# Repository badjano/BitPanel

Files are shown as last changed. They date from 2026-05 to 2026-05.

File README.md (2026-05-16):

# BitPanel

BitPanel is a small **open-source toy**: toggles set a **24-bit RGB** colour (8 bits per channel) on one LED, with a **Raspberry Pi Pico** (MicroPython) reading switches via shift registers and applying a few playful transforms.

This repo exists so **other people can build it**. Nothing here is sold or warranted—see **[Disclaimer](#disclaimer)** below.

**Play in the browser:** [https://badjano.github.io/BitPanel/](https://badjano.github.io/BitPanel/) (GitHub Pages — 24-bit RGB toggles, no install).

## Documentation

| Guide | Contents |
|---|---|
| **[web/README.md](web/README.md)** | Browser sim — 24 toggles, flip RGB bits (no hardware) |
| **[blender/README.md](blender/README.md)** | Parametric panel plate, STL export, printing and mechanical fit-up |
| **[pico/README.md](pico/README.md)** | Wiring (shift registers, buttons, NeoPixel), firmware, bring-up |
| **[blender/export/README.md](blender/export/README.md)** | Pre-built `bitpanel_plate.stl` (optional; regenerate from the script) |

## Parts (starting point)

| Item | Notes |
|---|---|
| Raspberry Pi Pico | MicroPython build with `neopixel` support |
| 74HC165 shift registers × 4 | Panel switch inputs (32 lines on default plate; **24 bits** drive RGB) |
| Toggles | **24** for colour (R/G/B × 8), or **32** on the default plate with eight spare / unmapped — match `BIT_PERM` in `pico/hw_config.py` |
| Tactile switches × 4 | Random / Organize / Shift up / Shift down |
| WS2812 (“NeoPixel”) LED × 1 | Or small NeoPixel PCB |
| Resistors | Pull-ups as needed (Pico has internal pulls on GPIO buttons) |
| Power | USB for Pico; NeoPixel level / voltage per your pixel datasheet |
| Fasteners | Panel screws for toggles; M3 or similar for corner holes if used |
| Wire, solder, perfboard or PCB | Optional custom PCB for shift registers |

Always measure **your** switch bushings and pixels before printing. See **[blender/README.md](blender/README.md)** for plate geometry.

## Assembly order (overview)

1. Print and dry-fit the plate — **[blender/README.md](blender/README.md)**
2. Mount toggles, mode buttons, and LED
3. Wire electronics and flash firmware — **[pico/README.md](pico/README.md)**
4. Tune `hw_config.py` and `PARAMETERS` in `bitpanel_case.py` to match your build

## Troubleshooting

| Symptom | Where to look |
|---|---|
| Wrong bit order | [pico/README.md](pico/README.md) — `SHIFT_MSB_FIRST`, `BIT_PERM` |
| Random flicker / bad reads | [pico/README.md](pico/README.md) — power, wiring length, clock vs data |
| LED wrong colour | [pico/README.md](pico/README.md) — RGB packing, NeoPixel wiring |
| Holes / fit wrong | [blender/README.md](blender/README.md) — `PARAMETERS`, re-export STL |

## Safety

- Double-check **power polarity** before applying USB or LED supply.
- NeoPixels can draw **surprising current** at full white — size wiring and USB supply accordingly.

## Licensing

- **Software** (`pico/`): **[MIT License](LICENSE)**
- **Hardware design materials** (`blender/` and derivatives): **[CERN-OHL-P-Version-2](LICENSE-HARDWARE)**

SPDX: `MIT` (software), `CERN-OHL-P-2.0` (hardware). If you redistribute adapted hardware designs, follow the notice requirements in **`LICENSE-HARDWARE`**.

## Disclaimer

**Use at your own risk.** BitPanel is **just a fun project**: hobby-grade firmware, generic mechanical assumptions, and no certification or compliance guarantees (electrical safety, EMC, eye safety from LEDs, etc.). You are responsible for how you power it, wire it, mount it, and who uses it. The authors and contributors are **not liable** for damage or injury arising from building or using this project.

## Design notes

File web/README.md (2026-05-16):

# BitPanel — web simulator

Simple browser version: **24 buttons** flip the bits of a **24-bit RGB** colour (same layout as [`pico/bits_ops.py`](../pico/bits_ops.py)).

**Play online:** [https://badjano.github.io/BitPanel/](https://badjano.github.io/BitPanel/)

| Bit index | Channel |
|---|---|
| 0–7 | Red |
| 8–15 | Green |
| 16–23 | Blue |

## Run locally

ES modules need a local server (opening `index.html` as `file://` may block imports).

```bash
cd web
python -m http.server 8080
```

Then open **http://localhost:8080/**

## GitHub Pages

Pushes to `main` deploy automatically via [`.github/workflows/pages.yml`](../.github/workflows/pages.yml).  
Repo **Settings → Pages → Build and deployment** should use **GitHub Actions** (enabled on first workflow run).

← **[Project overview](../README.md)**

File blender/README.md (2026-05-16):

# BitPanel — panel plate (Blender)

Parametric **top plate** for an **8×4** toggle grid (32 holes on the default layout), four mode buttons, one LED hole, corner mounts, and an underside **Pico pocket**. Firmware colour is **24-bit RGB** — wire **24** toggles to colour bits or map 32 positions via `pico/hw_config.py` (`BIT_PERM`).

← **[Project overview](../README.md)** · Firmware & wiring: **[pico/README.md](../pico/README.md)**

## Files

| File | Role |
|---|---|
| `bitpanel_case.py` | Build geometry; edit `PARAMETERS` at the top (millimetres) |
| `export/bitpanel_plate.stl` | Example export — see **[export/README.md](export/README.md)** |

## Interactive (Blender UI)

1. Install **Blender 3 LTS or newer** (4.x / 5.x is fine).
2. **Scripting** workspace → **Text → Open** → `bitpanel_case.py` → **Run Script**.

You get mesh **`BitPanel_Plate`**: **8×4** toggle holes, **four** button holes, **one** LED hole, **corner** through-holes, **Pico pocket** on the underside.

### Tune `PARAMETERS`

- `toggle_hole_d_mm` — panel hole for your toggle bushings  
- `hole_pitch_x_mm` / `hole_pitch_y_mm` — centre spacing  
- `btn_*` — mode button row position and diameters  
- `led_*` — LED hole position and diameter  
- `pico_pocket_*` — clearance under the plate (no screw bosses; use pads or a tray)

Export: select plate → **File → Export → STL** (or 3MF).

## Headless STL export

Regenerate without opening the UI:

```bash
blender --background --factory-startup --python blender/bitpanel_case.py
```

`--factory-startup` skips personal add-ons (many fail in `--background` without a GPU UI).

**Steam (Windows PowerShell):**

```powershell
& 'C:\Program Files (x86)\Steam\steamapps\common\Blender\blender.exe' --background --factory-startup --python 'path\to\BitPanel\blender\bitpanel_case.py'
```

Output: **`export/bitpanel_plate.stl`** (folder created automatically).

## Blender MCP (optional)

Blender MCP lets an IDE run Python in Blender (`execute_blender_code`). Typical flow:

1. Install the **Blender addon** from your MCP project → enable in **Edit → Preferences → Add-ons**.
2. Connect from Blender’s MCP sidebar.
3. In **Cursor**: **Settings → MCP → Add server** (follow your MCP package README).

You can run this script via MCP or paste `bitpanel_case.py` into an execute-code action. If MCP is unavailable, use the UI or headless command above.

## Mechanical assembly

1. **Print** the plate; remove supports; test **one** toggle hole and **one** button before mounting all 32.
2. **Mount toggles** from the front; note **which physical position is bit 0** (map in `pico/hw_config.py` via `BIT_PERM` if needed).
3. **Mount** four tactile mode switches.
4. **Install** LED from the front (diffuser optional).
5. **Mount Pico** under the panel (adhesive, standoffs, or separate tray — the script only cuts a **pocket**).
6. **USB** exit is not modelled by default — slot in CAD, drill, or file as needed.

Electronics and firmware: **[pico/README.md](../pico/README.md)**.

## License

Hardware design materials in this folder are under **[CERN-OHL-P-Version-2](../LICENSE-HARDWARE)**.

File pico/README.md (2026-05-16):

# BitPanel — Pico firmware & wiring

**MicroPython** on a **Raspberry Pi Pico**: read panel switches through **four 74HC165** shift registers, drive one **NeoPixel** from a **24-bit RGB** word (8 bits per channel), plus four **mode buttons** on GPIO.

← **[Project overview](../README.md)** · Panel plate: **[blender/README.md](../blender/README.md)**

## Firmware files

| File | Role |
|---|---|
| `main.py` | Main loop, buttons, LED update |
| `hw_config.py` | Pins, `SHIFT_MSB_FIRST`, `BIT_PERM` |
| `shift165.py` | Parallel load + clock in raw switch word (32 lines on default plate) |
| `bits_ops.py` | RGB pack/unpack, random / quantize / rotate |

### Behaviour

- **Panel** sets the baseline colour when any toggle changes.
- **Random** — new random 24-bit colour.
- **Organize** — quantize each RGB channel (steps of 32).
- **Shift up / down** — rotate the **24** RGB bits (colour stays in R/G/B space).

## Wiring

### Shift registers (panel switches, 3 Pico pins)

Four **74HC165** devices chained:

- **PL** (parallel load) — shared → `PIN_SR_PL` (default GP16), active-low load pulse.
- **CLK** — shared → `PIN_SR_CP` (GP17).
- **Serial chain**: **Q7** of chip *n* → serial **in** of chip *n+1*.
- First chip serial **in** often tied **LOW** (match `SHIFT_MSB_FIRST` in `hw_config.py`).
- **CE** / inhibit: enable shifting when clocking (often tied low).

Each ’165 latches eight toggles on **parallel load**; firmware clocks one edge per switch line and samples **DATA** (`shift165.py`). Only **24** mapped bits form the RGB colour (`BIT_PERM`, then `MASK24`).

**Ground**: common between Pico, registers, switches, and LED return.

**Debouncing**: simple stable double-read in firmware; add RC hardware if inputs bounce badly.

### Mode buttons (4×)

Direct GPIO, **internal pull-up**, active **LOW** (default GP20–GP23 in `hw_config.py`).

### NeoPixel

Default data **GP15**. Many pixels want **5 V** data; Pico is **3.3 V** — use a **level shifter**, a **3.3 V–tolerant** pixel, or follow your part’s datasheet. **GND** common with the Pico.

## Install firmware

1. Flash **MicroPython** for Raspberry Pi Pico from [micropython.org](https://micropython.org/download/RPI_PICO/).
2. Mount USB storage; copy all `pico/*.py` files to the Pico root (so `main.py` runs at boot).
3. Confirm **`neopixel`** is available on your build.

## Bring-up

1. Optional: comment out or limit `NeoPixel` writes until wiring is verified.
2. In **Thonny** or **rshell**, toggle one switch and inspect `read_raw()` / panel word after fixing bit order.
3. Wrong colours: adjust `BIT_PERM` / `SHIFT_MSB_FIRST`, or byte order in `bits_ops.word_to_rgb`.

## Troubleshooting

| Symptom | Things to check |
|---|---|
| Wrong bit order | `SHIFT_MSB_FIRST`, chain direction, `BIT_PERM` |
| Random flicker | Power, long data line, clock/load near NeoPixel data |
| Always 0 / 255 | PL polarity, clock idle, wrong pin in `hw_config.py` |
| LED wrong colour | GRB handled by library — test pure R, G, B patterns |

## License

Firmware in this folder is under the **[MIT License](../LICENSE)**.

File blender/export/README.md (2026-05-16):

# Exported plate mesh

| File | Description |
|---|---|
| `bitpanel_plate.stl` | Plate generated from default `PARAMETERS` in [`../bitpanel_case.py`](../bitpanel_case.py) |

← **[Blender guide](../README.md)** · **[Project overview](../../README.md)**

Regenerate after changing switch spacing or hole sizes:

```bash
blender --background --factory-startup --python blender/bitpanel_case.py
```

Commit an updated STL only if you want makers to skip Blender; otherwise they can export locally.

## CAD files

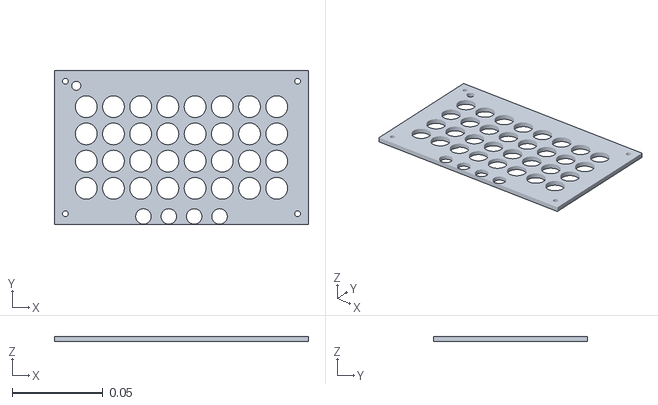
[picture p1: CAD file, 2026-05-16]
blender/export/bitpanel_plate.stl
0.14 x 0.085 x 0.003

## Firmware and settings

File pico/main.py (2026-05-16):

# SPDX-License-Identifier: MIT
"""
BitPanel controller: panel switches → 24-bit RGB NeoPixel, plus modifier buttons.

Colour is always 24 bits (R, G, B × 8). Shift registers may read more switch
lines; only the lower 24 bits are used for the LED after mapping (see MASK24).

Modifier actions (edge-triggered):
  Random     — replace working colour with random 24-bit RGB.
  Organize   — quantize RGB channels to steps (see bits_ops.organize_quantize_rgb).
  Shift up   — rotate the 24 RGB bits left by one (wraps within color bits).
  Shift down — rotate the 24 RGB bits right by one.

Base color follows the panel when switches change; modifiers rewrite ``working``.
"""

import time
from machine import Pin

from neopixel import NeoPixel

import bits_ops as bits
from hw_config import (
    BIT_PERM,
    DEBOUNCE_MS,
    MASK24,
    NEOPIXEL_COUNT,
    PIN_BTN_ORGANIZE,
    PIN_BTN_RANDOM,
    PIN_BTN_SHIFT_DOWN,
    PIN_BTN_SHIFT_UP,
    PIN_NEOPIXEL,
)
from shift165 import Shift165Chain, read_stable


class EdgeButton:
    def __init__(self, pin_num: int):
        self._pin = Pin(pin_num, Pin.IN, Pin.PULL_UP)
        self._debounced = self._pin.value()
        self._last_change = time.ticks_ms()

    def pressed_edge(self) -> bool:
        """True once when the debounced line settles to pressed (LOW)."""
        now = time.ticks_ms()
        raw = self._pin.value()
        if raw != self._debounced:
            if time.ticks_diff(now, self._last_change) >= DEBOUNCE_MS:
                self._debounced = raw
                self._last_change = now
                return raw == 0
            return False
        self._last_change = now
        return False


def push_led(np: NeoPixel, word: int) -> None:
    r, g, b = bits.word_to_rgb(word)
    np[0] = (r, g, b)
    np.write()


def main() -> None:
    chain = Shift165Chain(32)
    np = NeoPixel(Pin(PIN_NEOPIXEL), NEOPIXEL_COUNT)

    btn_random = EdgeButton(PIN_BTN_RANDOM)
    btn_org = EdgeButton(PIN_BTN_ORGANIZE)
    btn_up = EdgeButton(PIN_BTN_SHIFT_UP)
    btn_dn = EdgeButton(PIN_BTN_SHIFT_DOWN)

    panel_prev = -1
    working = 0

    while True:
        raw = read_stable(chain)
        panel = bits.apply_perm(raw, BIT_PERM) & MASK24

        # Panel drives baseline whenever toggled.
        if panel != panel_prev:
            panel_prev = panel
            working = panel

        if btn_random.pressed_edge():
            working = bits.random_word24()

        if btn_org.pressed_edge():
            working = bits.organize_quantize_rgb(working) & MASK24

        if btn_up.pressed_edge():
            working = bits.rol24(working, 1)

        if btn_dn.pressed_edge():
            working = bits.ror24(working, 1)

        push_led(np, working)
        time.sleep_ms(5)


if __name__ == "__main__":
    main()

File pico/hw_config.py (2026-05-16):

# SPDX-License-Identifier: MIT
"""
Hardware mapping for BitPanel + Raspberry Pi Pico (MicroPython).

Panel switches are read via four chained 74HC165 SIPO shift registers
(8 bits each; 32 lines total on the default 8×4 plate). The LED uses a
24-bit RGB word (bits 0–23). Tune SHIFT_MSB_FIRST to match your wiring.

NeoPixel: one WS2812-class LED on a single GPIO (GRB order handled by library).

Action buttons: direct GPIO with internal pull-ups, active LOW.
"""

# 74HC165 → Pico
PIN_SR_PL = 16  # parallel load (active low on 165)
PIN_SR_CP = 17  # clock
PIN_SR_DATA = 18  # serial out Q7 from last chip in chain

# WS2812 data line
PIN_NEOPIXEL = 15
NEOPIXEL_COUNT = 1

# Shift-register serial order (hardware read, not RGB bit count).
# True: first clock bit is MSB of the raw shift word (common with some layouts).
SHIFT_MSB_FIRST = True

# Map logical RGB bit index → physical switch index on the shift chain.
# Length 24: one entry per colour bit (R low byte, then G, then B).
BIT_PERM = tuple(range(24))

# Direct buttons (active LOW)
PIN_BTN_RANDOM = 20
PIN_BTN_ORGANIZE = 21
PIN_BTN_SHIFT_UP = 22
PIN_BTN_SHIFT_DOWN = 23

# Debouncing
DEBOUNCE_MS = 25
SHIFT_READ_DELAY_US = 2
